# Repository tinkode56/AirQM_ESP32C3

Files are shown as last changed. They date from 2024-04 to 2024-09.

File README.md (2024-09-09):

| Supported Targets | ESP32-C3 |
| --- | --- |

# AirQM_ESP32C3

Air quality monitor using ESP32-C3 and sensors to measure temperature, relative humidity, dust particles, CO2, VOC and NOx.

## Components used

|Item |Buy link |
|---|---|
| ESP32-C3 SuperMini | [Aliexpress](https://www.aliexpress.com/item/1005006451672646.html) |
| senseAir S8 004-0-0053 | [Aliexpress](https://www.aliexpress.com/item/1005005225848074.html) |
| PMS5003 | [Aliexpress](https://www.aliexpress.com/item/1005005967735332.html) |
| SHT45 | [Aliexpress](https://www.aliexpress.com/item/1005003742319869.html) |
| SGP41 | [Aliexpress](https://www.aliexpress.com/item/4000037083952.html) |
| Oled Display | [Aliexpress](https://www.aliexpress.com/item/32950307344.html) |
| Magnets (5x3mm) | [Aliexpress](https://www.aliexpress.com/item/1005001529831924.html) |
| M2 set (M2A) | [Aliexpress](https://www.aliexpress.com/item/1005005467831636.html) |

## Hardware
```
Neodim magnet: 5mm diameter, 3mm height
Heat insert: M2 x 3 x 3.2 for main board
Screws: M2 for PMS5003
```

## Pin connection matrix

```
| ESP32-C3 |  OLED   |  SGP41  |  SHT45  | Senseair S8 | PMS5003  | WS2812 |
|----------|---------|---------|---------|-------------|----------|--------|
| GND      | Pin GND | Pin GND | Pin GND | G0          | PIN2 GND |        |
| 3V3      | Pin 3V3 | Pin 3V3 | Pin 3V3 |             |          |        |
| 5V       |         |         |         | G+          | PIN1 VCC |        |
| GPIO_0   |         |         |         |             | PIN4 TX  |        |
| GPIO_1   |         |         |         |             | PIN5 RX  |        |
| GPIO_2   |         |         |         |             |          |        |
| GPIO_3   |         |         |         |             |          |  DATA  |
| GPIO_4   | Pin SCK |         |         |             |          |        |
| GPIO_5   | Pin DC  |         |         |             |          |        |
| GPIO_6   | Pin SDA |         |         |             |          |        |
| GPIO_7   | Pin CS  |         |         |             |          |        |
| GPIO_8   |         | Pin SDA | Pin SDA |             |          |        |
| GPIO_9   |         | Pin SCL | Pin SCL |             |          |        |
| GPIO_10  | Pin RES |         |         |             |          |        |
| GPIO_20  |         |         |         | UART_TxD    |          |        |
| GPIO_21  |         |         |         | UART_RxD    |          |        |
```

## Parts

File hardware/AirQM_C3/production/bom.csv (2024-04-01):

Designator | Footprint | Quantity | Value | LCSC Part #
C1, C10, C11, C2, C3, C4, C5, C6, C7, C8, C9 | 0603 | 11 | 0.1u
D1 | 0805 | 1 | Alarm_LED
D10, D11, D12, D3, D4, D5, D6, D7, D8, D9 | ws2812_airqm | 10 | WS2812B
D2 | 0805 | 1 | PWM_LED
J1 | PinSocket_1x06_P2.54mm_Vertical | 1 | PMS5003 adapt
J2 | Molex_PicoBlade_53261-0871_1x08-1MP_P1.25mm_Horizontal | 1 | PMS5003
J3 | PinSocket_1x04_P2.54mm_Vertical | 1 | SHT45
J4 | PinSocket_1x04_P2.54mm_Vertical | 1 | SGP41
J5 | PinSocket_1x04_P2.54mm_Vertical | 1 | Spare I2C
J6 | PinSocket_1x07_P2.54mm_Vertical | 1 | OLED
R1, R2 | 0805 | 2 | 4.7k
R3, R4 | 0805 | 2 | 10k
SW1, SW2 | tactile_switch_airqm | 2 | SW_Push
U1 | MODULE_ESP32-C3_SUPERMINI | 1 | ESP32-C3_SUPERMINI
U2 | Senseair_S8_Up | 1 | 004-0-0053

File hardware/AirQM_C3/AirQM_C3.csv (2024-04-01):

Reference | Value | Datasheet | Footprint | Qty | DNP
C1,C2,C3,C4,C5,C6,C7,C8,C9,C10,C11 | 0.1u | ~ | Capacitor_SMD:C_0603_1608Metric | 11
D1 | Alarm_LED | ~ | LED_SMD:LED_0805_2012Metric | 1
D2 | PWM_LED | ~ | LED_SMD:LED_0805_2012Metric | 1
D3,D4,D5,D6,D7,D8,D9,D10,D11,D12 | WS2812B | https://cdn-shop.adafruit.com/datasheets/WS2812B.pdf | ws2812_airqm:ws2812_airqm | 10
J1 | PMS5003 adapt | ~ | Connector_PinSocket_2.54mm:PinSocket_1x06_P2.54mm_Vertical | 1
J2 | PMS5003 | ~ | Connector_Molex:Molex_PicoBlade_53261-0871_1x08-1MP_P1.25mm_Horizontal | 1
J3 | SHT45 | ~ | Connector_PinSocket_2.54mm:PinSocket_1x04_P2.54mm_Vertical | 1
J4 | SGP41 | ~ | Connector_PinSocket_2.54mm:PinSocket_1x04_P2.54mm_Vertical | 1
J5 | Spare I2C | ~ | Connector_PinSocket_2.54mm:PinSocket_1x04_P2.54mm_Vertical | 1
J6 | OLED | ~ | Connector_PinSocket_2.54mm:PinSocket_1x07_P2.54mm_Vertical | 1
R1,R2 | 4.7k | ~ | Resistor_SMD:R_0805_2012Metric | 2
R3,R4 | 10k | ~ | Resistor_SMD:R_0805_2012Metric | 2
SW1,SW2 | SW_Push | ~ | tactile_switch_airqm:tactile_switch_airqm | 2
U1 | ESP32-C3_SUPERMINI |  | esp32c3_supermini:MODULE_ESP32-C3_SUPERMINI | 1
U2 | 004-0-0053 | https://rmtplusstoragesenseair.blob.core.windows.net/docs/publicerat/PSP126.pdf | Sensor:Senseair_S8_Up | 1

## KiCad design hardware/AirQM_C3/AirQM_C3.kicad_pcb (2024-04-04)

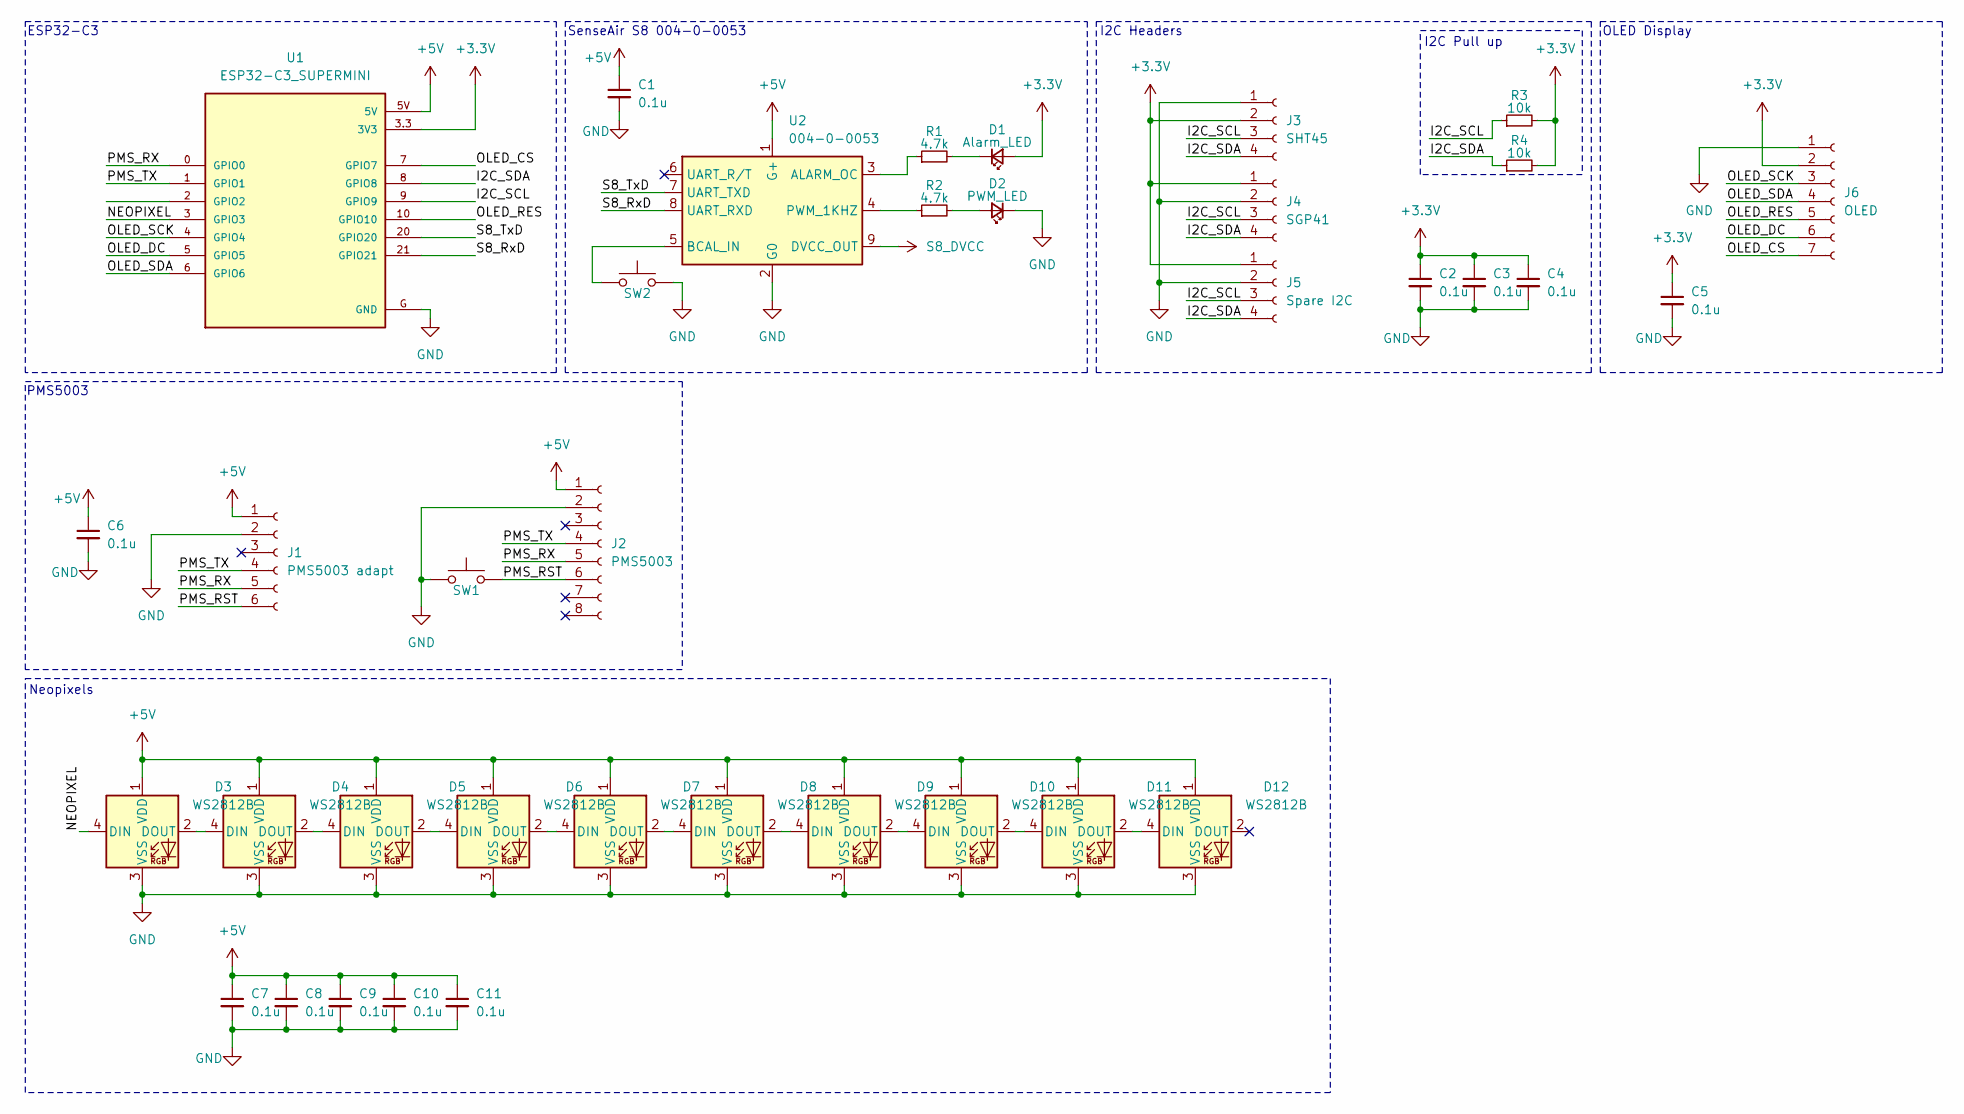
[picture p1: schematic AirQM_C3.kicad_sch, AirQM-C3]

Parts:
C1, C2, C3, C4, C5, C6, C7, C8, C9, C10, C11: 0.1u; C_0603_1608Metric
D1: Alarm_LED; LED_0805_2012Metric
D2: PWM_LED; LED_0805_2012Metric
D3, D4, D5, D6, D7, D8, D9, D10, D11, D12: WS2812B; ws2812_airqm
J1: PMS5003 adapt; PinSocket_1x06_P2.54mm_Vertical
J2: PMS5003; Molex_PicoBlade_53261-0871_1x08-1MP_P1.25mm_Horizontal
J3: SHT45; PinSocket_1x04_P2.54mm_Vertical
J4: SGP41; PinSocket_1x04_P2.54mm_Vertical
J5: Spare I2C; PinSocket_1x04_P2.54mm_Vertical
J6: OLED; PinSocket_1x07_P2.54mm_Vertical
R1, R2: 4.7k; R_0805_2012Metric
R3, R4: 10k; R_0805_2012Metric
SW1, SW2: SW_Push; tactile_switch_airqm
U1: ESP32-C3_SUPERMINI; MODULE_ESP32-C3_SUPERMINI
U2: 004-0-0053; Senseair_S8_Up

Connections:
+3.3V: C2.1, C3.1, C4.1, C5.1, D1.2 (A), J3.2, J4.1, J5.1, J6.2, R3.2, R4.2, U1.3.3 (3V3)
+5V: C1.1, C6.1, C7.1, C8.1, C9.1, C10.1, C11.1, D3.1 (VDD), D4.1 (VDD), D5.1 (VDD), D6.1 (VDD), D7.1 (VDD), D8.1 (VDD), D9.1 (VDD), D10.1 (VDD), D11.1 (VDD), D12.1 (VDD), J1.1, J2.1, U1.5V, U2.1 (G+)
/I2C_SCL: J3.3, J4.3, J5.3, R3.1, U1.9 (GPIO9)
/I2C_SDA: J3.4, J4.4, J5.4, R4.1, U1.8 (GPIO8)
/NEOPIXEL: D3.4 (DIN), U1.3 (GPIO3)
/OLED_CS: J6.7, U1.7 (GPIO7)
/OLED_DC: J6.6, U1.5 (GPIO5)
/OLED_RES: J6.5, U1.10 (GPIO10)
/OLED_SCK: J6.3, U1.4 (GPIO4)
/OLED_SDA: J6.4, U1.6 (GPIO6)
/PMS_RST: J1.6, J2.6, SW1.2
/PMS_RX: J1.5, J2.5, U1.0 (GPIO0)
/PMS_TX: J1.4, J2.4, U1.1 (GPIO1)
/S8_RxD: U1.21 (GPIO21), U2.8 (UART_RXD)
/S8_TxD: U1.20 (GPIO20), U2.7 (UART_TXD)
GND: C1.2, C2.2, C3.2, C4.2, C5.2, C6.2, C7.2, C8.2, C9.2, C10.2, C11.2, D2.1 (K), D3.3 (VSS), D4.3 (VSS), D5.3 (VSS), D6.3 (VSS), D7.3 (VSS), D8.3 (VSS), D9.3 (VSS), D10.3 (VSS), D11.3 (VSS), D12.3 (VSS), J1.2, J2.2, J2.MP, J3.1, J4.2, J5.2, J6.1, SW1.1, SW2.2, U1.G (GND), U2.2 (G0)
unnamed: D1.1 (K), R1.2
unnamed: D2.2 (A), R2.2
unnamed: D3.2 (DOUT), D4.4 (DIN)
unnamed: D4.2 (DOUT), D5.4 (DIN)
unnamed: D5.2 (DOUT), D6.4 (DIN)
unnamed: D6.2 (DOUT), D7.4 (DIN)
unnamed: D7.2 (DOUT), D8.4 (DIN)
unnamed: D8.2 (DOUT), D9.4 (DIN)
unnamed: D9.2 (DOUT), D10.4 (DIN)
unnamed: D10.2 (DOUT), D11.4 (DIN)
unnamed: D11.2 (DOUT), D12.4 (DIN)
unnamed: R1.1, U2.3 (ALARM_OC)
unnamed: SW2.1, U2.5 (BCAL_IN)
unnamed: R2.1, U2.4 (PWM_1KHZ)
S8_DVCC: U2.9 (DVCC_OUT)

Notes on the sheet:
I2C Pull up
I2C Headers
PMS5003
SenseAir S8 004-0-0053
Neopixels
OLED Display
ESP32-C3

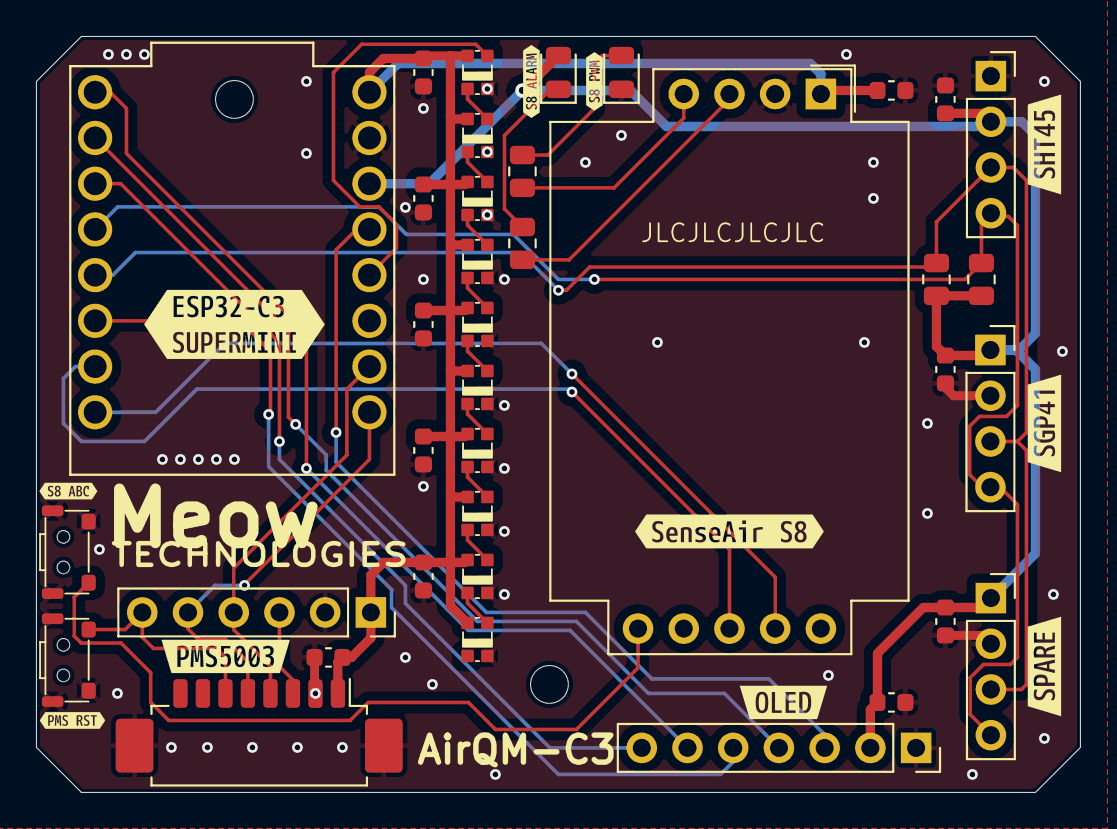
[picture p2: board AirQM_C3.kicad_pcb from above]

Board: 2 copper layers, 58.0 x 42.0 mm, 48 parts (0 on the bottom side), 30 nets.

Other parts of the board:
kibuzzard-660842A3: G***; kibuzzard-660842A3
kibuzzard-660842BE: G***; kibuzzard-660842BE
kibuzzard-660842DD: G***; kibuzzard-660842DD
kibuzzard-660842F1: G***; kibuzzard-660842F1
kibuzzard-6608425C: G***; kibuzzard-6608425C
kibuzzard-6608431D: G***; kibuzzard-6608431D
kibuzzard-66084205: G***; kibuzzard-66084205
kibuzzard-66084210: G***; kibuzzard-66084210
kibuzzard-66084234: G***; kibuzzard-66084234
kibuzzard-66084249: G***; kibuzzard-66084249
kibuzzard-66084324: G***; kibuzzard-66084324

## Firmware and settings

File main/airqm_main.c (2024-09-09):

/*
 * @Author: calin.acr 
 * @Date: 2024-03-15 14:00:51 
 * @Last Modified by: calin.acr
 * @Last Modified time: 2024-09-09 22:23:18
 */

#include <stdio.h>
#include <inttypes.h>
#include "sdkconfig.h"
#include "freertos/FreeRTOS.h"
#include "freertos/task.h"
#include "esp_chip_info.h"
#include "esp_flash.h"
#include "esp_system.h"
#include "oled_display.h"
#include "sgp41.h"
#include "sht45.h"
#include "string.h"
#include "esp_timer.h"
#include "esp_random.h"
#include "sensirion_gas_index_algorithm.h"
#include "senseair_s8.h"
#include "airqm_main.h"
#include "pms5003.h"
#include "nvs_flash.h"
#include "airqm_wifi.h"
#include "airqm_influxdb.h"
#include "esp_sntp.h"
#include "esp_netif_sntp.h"
#include "led_strip.h"
#include "board_support.h"

QueueHandle_t i2cdev_queue;
QueueHandle_t s8_queue;
QueueHandle_t pms_queue;
QueueHandle_t oled_queue;
QueueHandle_t influxdb_queue;

TaskHandle_t xOledTaskHandle = NULL;
TaskHandle_t xI2CDevTaskHandle = NULL;
TaskHandle_t xSenseairTaskHandle = NULL;
TaskHandle_t xPMSTaskHandle = NULL;
TaskHandle_t xDataManagerHandle = NULL;
TaskHandle_t xInfluxManagerHandle = NULL;
TaskHandle_t xNeopixelManagerHandle = NULL;

/* Task stack sizes in bytes */
const uint16_t oled_stack_size = 3000;
const uint16_t i2c_stack_size = 3000;
const uint16_t senseair_stack_size = 2800;
const uint16_t pms_stack_size = 2800;
const uint16_t datmgr_stack_size = 1500;
const uint16_t influx_stack_size = 5000;
const uint16_t neopixel_stack_size = 3000;


void vOledTask(void *pvParameters);
void vI2CDevTask(void *pvParameters);
void vSenseairTask(void *pvParameters);
void vDataManagerTask(void *pvParameters);
void vInfluxDBManagerTask(void *pvParameters);
void vNeopixelManagerTask(void *pvParameters);

void SyncTime(void);


void app_main(void)
{
    /* Initialize display and set the splash screen */
    oled_init();
    // Wifi provisioning and connection init
    airqm_wifiprov_init();

    // Synchronize time from internet
    SyncTime();

    // Create queue between i2c and oled task
    i2cdev_queue = xQueueCreate(3, sizeof(struct I2CDevMessage *));
    s8_queue = xQueueCreate(3, sizeof(uint16_t));
    pms_queue = xQueueCreate(3, sizeof(struct PMSData *));
    oled_queue = xQueueCreate(3, sizeof(AirQM_metrics));
    influxdb_queue = xQueueCreate(3, sizeof(AirQM_metrics));
    
    // Initialize the I2C master bus
    i2c_master_bus_config_t conf = {
        .clk_source = I2C_CLK_SRC_DEFAULT,
        .i2c_port = I2C_NUM_0,
        .sda_io_num = AIRQM_I2C_SDA,
        .scl_io_num = AIRQM_I2C_SCL,
        .glitch_ignore_cnt = 7,
        .flags.enable_internal_pullup = true,
    };
    i2c_master_bus_handle_t bus_handle;
    ESP_ERROR_CHECK(i2c_new_master_bus(&conf, &bus_handle));

    // xTaskCreate(vNeopixelManagerTask, "Neopixel TASK", neopixel_stack_size, NULL, tskAIRQM_NEOPIXEL_PRIORITY, &xNeopixelManagerHandle);
    // configASSERT(xNeopixelManagerHandle);

    xTaskCreate(vDataManagerTask, "DataMgr TASK", datmgr_stack_size, NULL, tskAIRQM_DATAMGR_PRIORITY, &xDataManagerHandle);
    configASSERT(xDataManagerHandle);

    xTaskCreate(vInfluxDBManagerTask, "InfluxMgr TASK", influx_stack_size, NULL, tskAIRQM_INFLUX_PRIORITY, &xInfluxManagerHandle);
    configASSERT(xInfluxManagerHandle);

    xTaskCreate(vI2CDevTask, "I2CDev TASK", i2c_stack_size, (void *)bus_handle, tskAIRQM_I2C_PRIORITY, &xI2CDevTaskHandle);
    configASSERT(xI2CDevTaskHandle);

    xTaskCreate(vOledTask, "OLED TASK", oled_stack_size, NULL, tskAIRQM_DISPLAY_PRIORITY, &xOledTaskHandle);
    configASSERT(xOledTaskHandle);

    xTaskCreate(vSenseairTask, "SENSEAIR TASK", senseair_stack_size, NULL, tskAIRQM_CO2_PRIORITY, &xSenseairTaskHandle);
    configASSERT(xSenseairTaskHandle);

    xTaskCreate(PMS_MainTask, "PMS5003 TASK", pms_stack_size, (void *)pms_queue, tskAIRQM_PMS_PRIORITY, &xPMSTaskHandle);
    configASSERT(xPMSTaskHandle);

    for ( ;; )
    {
        /* Stack size measurements */
        ESP_LOGE("APP_MAIN", "Oled task stack unused bytes: %d", uxTaskGetStackHighWaterMark(xOledTaskHandle));
        ESP_LOGE("APP_MAIN", "I2C task stack unused bytes: %d", uxTaskGetStackHighWaterMark(xI2CDevTaskHandle));
        ESP_LOGE("APP_MAIN", "Senseair task stack unused bytes: %d", uxTaskGetStackHighWaterMark(xSenseairTaskHandle));
        ESP_LOGE("APP_MAIN", "PMS5003 task stack unused bytes: %d", uxTaskGetStackHighWaterMark(xPMSTaskHandle));
        ESP_LOGE("APP_MAIN", "DataMgr task stack unused bytes: %d", uxTaskGetStackHighWaterMark(xDataManagerHandle));
        ESP_LOGE("APP_MAIN", "InfluxMgr task stack unused bytes: %d", uxTaskGetStackHighWaterMark(xInfluxManagerHandle));
        ESP_LOGE("APP_MAIN", "NeopixelMgr task stack unused bytes: %d", uxTaskGetStackHighWaterMark(xNeopixelManagerHandle));
        vTaskDelay(pdMS_TO_TICKS(5000));
    }
}

void vOledTask(void *pvParameters)
{
    ESP_LOGW("OLED_TASK", "Task started");
    
    char temp_buff[7] = "wait  ";
    char hum_buff[7] = "wait  ";
    char co2_buff[6] = "wait ";
    char pm10_buff[6] = "wait ";
    char pm25_buff[6] = "wait ";
    char pm100_buff[6] = "wait ";
    char tvoc_buff[6] = "wait ";
    char nox_buff[6] = "wait ";

    AirQM_metrics allMetrics = { 0 };

    oled_clear_display_buffer();
    
    oled_draw_text("AirQM -> Meow TECH", 0, 1);

    oled_draw_text(temp_buff, 1, 0);
    oled_draw_text("~C", 1, 6);
    oled_draw_text(hum_buff, 1, 12);
    oled_draw_text("%RH", 1, 18);
    
    oled_draw_text("CO2", 2, 0);
    oled_draw_text(co2_buff, 2, 7);
    oled_draw_text("ppm", 2, 14);

    oled_draw_text("PM1.0", 3, 0);
    oled_draw_text(pm10_buff, 3, 7);
    oled_draw_text("ug/m3", 3, 14);

    oled_draw_text("PM2.5", 4, 0);
    oled_draw_text(pm25_buff, 4, 7);
    oled_draw_text("ug/m3", 4, 14);

    oled_draw_text("PM10", 5, 0);
    oled_draw_text(pm100_buff, 5, 7);
    oled_draw_text("ug/m3", 5, 14);

    oled_draw_text("VOC", 6, 0);
    oled_draw_text(tvoc_buff, 6, 7);

    oled_draw_text("NOx", 7, 0);
    oled_draw_text(nox_buff, 7, 7);

    oled_flush();

    for( ;; )
    {
        // Task body
        if (oled_queue != 0)
        {
            if (xQueueReceive(oled_queue, &(allMetrics), (TickType_t) 10))
            {
                // Convert values to strings
                sprintf(temp_buff, "%6.2f", allMetrics.temp_phy);
                sprintf(hum_buff, "%6.2f", allMetrics.hum_phy);
                sprintf(tvoc_buff, "%5ld", allMetrics.voc_index_value);
                sprintf(nox_buff, "%5ld", allMetrics.nox_index_value);
                sprintf(co2_buff, "%5d", allMetrics.co2_val);
                sprintf(pm10_buff, "%5d", allMetrics.pm10_std);
                sprintf(pm25_buff, "%5d", allMetrics.pm25_std);
                sprintf(pm100_buff, "%5d", allMetrics.pm100_std);
                // Write to GDDRAM
                oled_draw_text(temp_buff, 1, 0);
                oled_draw_text(hum_buff, 1, 12);
                oled_draw_text(tvoc_buff, 6, 7);
                oled_draw_text(nox_buff, 7, 7);
                oled_draw_text(co2_buff, 2, 7);
                oled_draw_text(pm10_buff, 3, 7);
                oled_draw_text(pm25_buff, 4, 7);
                oled_draw_text(pm100_buff, 5, 7);
                // Flush GDDRAM to display
                oled_flush();
            }
            
        }
    }
}

void vI2CDevTask(void *pvParameters)
{
    ESP_LOGW("I2C TASK", "Task started");

    struct I2CDevMessage *pxMessage;
    i2c_master_bus_handle_t bus_handle;

    bus_handle = (i2c_master_bus_handle_t) pvParameters;
    pxMessage = &xI2CDevMessage;

    uint8_t conditioning_counter = 0;

    uint16_t sht45_temp_raw;
    uint16_t sht45_hum_raw;
    uint16_t sgp41_voc_raw;
    uint16_t sgp41_nox_raw;

    GasIndexAlgorithmParams voc_params;
    GasIndexAlgorithmParams nox_params;

    GasIndexAlgorithm_init(&voc_params, GasIndexAlgorithm_ALGORITHM_TYPE_VOC);
    GasIndexAlgorithm_init(&nox_params, GasIndexAlgorithm_ALGORITHM_TYPE_NOX);

    // SHT45 init and reset
    SHT45_Init(&bus_handle);
    SHT45_SoftReset();


    // SGP41 init
    SGP41_Init(&bus_handle);

    // SGP41 conditioning (1 command every second, max 10 seconds)
    while (conditioning_counter < 10)
    {
        SGP41_ExecuteConditioning(&sgp41_voc_raw);
        // Count as conditioning iteration done
        conditioning_counter++;
        // Wait one second
        vTaskDelay(pdMS_TO_TICKS(1000));
    }
    
    for ( ;; )
    {
        // Task body
        // Read data from I2C sensors
        SHT45_Read(SHT45_MODE_HIGH_PRECISION_NO_HEATER, &sht45_temp_raw, &pxMessage->temp_phy, &sht45_hum_raw, &pxMessage->hum_phy);
        SGP41_MeasureRawSignals(sht45_temp_raw, sht45_hum_raw, &sgp41_voc_raw, &sgp41_nox_raw);

        // ESP_LOGI("SGP", "RAW VOC %d, NOx %d", sgp41_voc_raw, sgp41_nox_raw);

        // Use Sensirion Algorithm to get VOC and NOx indices
        GasIndexAlgorithm_process(&voc_params, sgp41_voc_raw, &pxMessage->voc_index_value);
        GasIndexAlgorithm_process(&nox_params, sgp41_nox_raw, &pxMessage->nox_index_value);
        
        // ESP_LOGI("SGP", "VOC %ld, NOx %ld", pxMessage->voc_index_value, pxMessage->nox_index_value);

        if (i2cdev_queue != 0)
        {
            if(xQueueSendToBack(i2cdev_queue, (void *) &pxMessage, (TickType_t) 0) != pdPASS)
            {
                ESP_LOGE("I2C TASK", "Failed to post the message");
            }
        }
        
        vTaskDelay(pdMS_TO_TICKS(1000));
        

        // taskYIELD();
    }
}


void vSenseairTask(void *pvParameters)
{
    ESP_LOGW("S8 TASK", "Task started");
    // uint8_t cal_status;
    uint16_t co2_value, status;
    uint16_t abc, memmap_ver, fw_ver;
    uint32_t sens_type_id, sens_id;
    
    SenseairS8_Init();
    
    // cal_status = S8_BgCalibration(CO2_BG_CAL);
    // ESP_LOGI("S8 TASK", "Calibration status %d", cal_status);
    
    S8_ReadSensorTypeID(&sens_type_id);
    ESP_LOGI("S8 TASK", "Sensor Type ID 0x%08jx", (uintmax_t)sens_type_id);

    S8_ReadABC(&abc);
    ESP_LOGI("S8 TASK", "ABC period 0x%04x, %d hours", abc, abc);

    S8_ReadMemMapVers(&memmap_ver);
    ESP_LOGI("S8 TASK", "Memory Mapping ver 0x%04x", memmap_ver);

    S8_ReadFWVers(&fw_ver);
    ESP_LOGI("S8 TASK", "Firmware ver 0x%04x", fw_ver);

    S8_ReadSensorID(&sens_id);
    ESP_LOGI("S8 TASK", "Sensor ID (SN) 0x%08jx", (uintmax_t)sens_id);
    
    for( ;; )
    {
        vTaskDelay(pdMS_TO_TICKS(4000));
        S8_ReadCO2andStatus(&co2_value, &status);
        
        if ((s8_queue != 0) && (!CHECK_ERROR_ANY(status)))
        {
            if (xQueueSendToBack(s8_queue, (void *) &co2_value, (TickType_t) 0) != pdTRUE)
            {
                ESP_LOGE("S8 TASK", "Failed to post the message");
            }
        }
    }
}

void SyncTime(void)
{
    // Synchronize time with NTP
    if ( esp_sntp_enabled() ) {
        esp_sntp_stop();
    }
    esp_sntp_setoperatingmode(ESP_SNTP_OPMODE_POLL);
    ESP_LOGI("NTP-Sync", "Getting time via NTP from: %s", CONFIG_AIRQM_NTP_SERVER);
    esp_sntp_setservername(0, CONFIG_AIRQM_NTP_SERVER);
    
    const int total_max_retries = 3;
    int total_retries = 0;
    time_t now = 0;
    struct tm timeinfo = { 0 };
    do {
        esp_sntp_init();

        int retry = 0;

        // NTP request is sent every 15 seconds, so wait 25 seconds for sync.
        const int retry_count = 10;
        while ((sntp_get_sync_status() == SNTP_SYNC_STATUS_RESET) && (++retry < retry_count)) {
            ESP_LOGI("NTP-Sync", "Waiting for system time to be set... (%d/%d)", retry, retry_count);
            vTaskDelay(2000 / portTICK_PERIOD_MS);
        }
        if (retry == retry_count) {
            total_retries += 1;
            esp_sntp_stop();
        } else {
            break;
        }
    } while (total_retries < total_max_retries);
    assert(total_retries < total_max_retries);
    // update 'now' variable with current time
    time(&now);

    // Set timezone
    ESP_LOGI("NTP-Sync", "Timezone is set to: %s", CONFIG_AIRQM_NTP_TZ);
    setenv("TZ", CONFIG_AIRQM_NTP_TZ, 1);
    tzset();
    localtime_r(&now, &timeinfo);

    char strftime_buf[64];
    strftime(strftime_buf, sizeof(strftime_buf), "%c", &timeinfo);
    ESP_LOGI("NTP-Sync", "The current date/time is: %s", strftime_buf);

}

void vDataManagerTask(void *pvParameters)
{
    struct I2CDevMessage *pxMessage;
    uint16_t co2_ppm;
    struct PMSRecvMessage *pxPMSMessage;

    AirQM_metrics allMetrics = { 0 };
    bool isAnyMetricUpdated = false;

    TickType_t xLastWakeTime;
    // Frequency of data write in InfluxDB (1 min = 60000 ms)
    const TickType_t xFrequency = pdMS_TO_TICKS(60000);

    xLastWakeTime = xTaskGetTickCount();

    for ( ;; )
    {
        if (i2cdev_queue != 0)
        {
            if (xQueueReceive(i2cdev_queue, &(pxMessage), (TickType_t) 10))
            {
                // Update allMetrict to be sent to InfluxDB
                allMetrics.temp_phy = pxMessage->temp_phy;
                allMetrics.hum_phy = pxMessage->hum_phy;
                allMetrics.voc_index_value = pxMessage->voc_index_value;
                allMetrics.nox_index_value = pxMessage->nox_index_value;
                // Signal metric values have updated
                isAnyMetricUpdated = true;
            }
        }

        if (s8_queue != 0)
        {
            if (xQueueReceive(s8_queue, &co2_ppm, (TickType_t) 10))
            {
                // Update allMetrict to be sent to InfluxDB
                allMetrics.co2_val = co2_ppm;
                // Signal metric values have updated
                isAnyMetricUpdated = true;
            }
        }

        if (pms_queue != 0)
        {
            if (xQueueReceive(pms_queue, &(pxPMSMessage), (TickType_t) 10))
            {
                // Update allMetrict to be sent to InfluxDB
                allMetrics.pm10_std = pxPMSMessage->pm10_std;
                allMetrics.pm25_std = pxPMSMessage->pm25_std;
                allMetrics.pm100_std = pxPMSMessage->pm100_std;
                allMetrics.pm10_env = pxPMSMessage->pm10_env;
                allMetrics.pm25_env = pxPMSMessage->pm25_env;
                allMetrics.pm100_env = pxPMSMessage->pm100_env;
                allMetrics.particles_03um = pxPMSMessage->particles_03um;
                allMetrics.particles_05um = pxPMSMessage->particles_05um;
                allMetrics.particles_10um = pxPMSMessage->particles_10um;
                allMetrics.particles_25um = pxPMSMessage->particles_25um;
                allMetrics.particles_50um = pxPMSMessage->particles_50um;
                allMetrics.particles_100um = pxPMSMessage->particles_100um;
                // Signal metric values have updated
                isAnyMetricUpdated = true;
            }
        }

        if (isAnyMetricUpdated)
        {
            // Send data to OLED
            if (oled_queue != 0)
            {
                if(xQueueSendToBack(oled_queue, (void *) &allMetrics, (TickType_t) 0) != pdPASS)
                {
                    ESP_LOGE("AqmDataManager", "Failed to post the message to oled queue");
                }
                else
                {
                    isAnyMetricUpdated = false;
                }
            }
        }

        if (xTaskGetTickCount() - xLastWakeTime >= xFrequency)
        {
            // Send data to InfluxDB Manager
            if (influxdb_queue != 0)
            {
                if(xQueueSendToBack(influxdb_queue, (void *) &allMetrics, (TickType_t) 0) != pdPASS)
                {
                    ESP_LOGE("AqmDataManager", "Failed to post the message to influxdb queue");
                }
            }
            // Update last wake time with current time
            xLastWakeTime = xTaskGetTickCount();
        }
    }
    
}

void vInfluxDBManagerTask(void *pvParameters)
{
    AirQM_metrics allMetrics = { 0 };

    for ( ;; )
    {
        if (influxdb_queue != 0)
        {
            if (xQueueReceive(influxdb_queue, &(allMetrics), (TickType_t) 10))
            {
                // Write data into InfluxDB
                write_influxdb(&allMetrics);
            }
        }
    }
}

#define PIXEL_COUNT 10

void vNeopixelManagerTask(void *pvParameters)
{  
    ESP_LOGW("NEOPIXEL TASK", "Task started");

    /* LED strip initialization with the GPIO and pixels number*/
    led_strip_config_t strip_config = {
        .strip_gpio_num = AIRQM_NEOPIXEL_PIN, // The GPIO that connected to the LED strip's data line
        .max_leds = PIXEL_COUNT, // The number of LEDs in the strip,
        .led_pixel_format = LED_PIXEL_FORMAT_GRB, // Pixel format of your LED strip
        .led_model = LED_MODEL_WS2812, // LED strip model
        .flags.invert_out = false, // whether to invert the output signal (useful when your hardware has a level inverter)
    };

    led_strip_rmt_config_t rmt_config = {
        .clk_src = RMT_CLK_SRC_DEFAULT, // different clock source can lead to different power consumption
        .resolution_hz = 10 * 1000 * 1000, // 10MHz
        .flags.with_dma = false, // whether to enable the DMA feature
    };

    // LED Strip object handle
    led_strip_handle_t led_strip;
    ESP_ERROR_CHECK(led_strip_new_rmt_device(&strip_config, &rmt_config, &led_strip));
    ESP_LOGI("NEOPIXEL TASK", "Created LED strip object with RMT backend");
    uint8_t colors[30] = {
        0x10, 0x00, 0x00, //LED0
        0x10, 0x08, 0x00, //LED1
        0x10, 0x10, 0x00, //LED2
        0x08, 0x10, 0x00, //LED3
        0x00, 0x10, 0x00, //LED4
        0x00, 0x10, 0x08, //LED5
        0x00, 0x10, 0x10, //LED6
        0x00, 0x08, 0x10, //LED7
        0x00, 0x00, 0x10, //LED8
        0x08, 0x00, 0x10  //LED9
        };

    for (int i = 0; i < PIXEL_COUNT; i++) {
        ESP_ERROR_CHECK(led_strip_set_pixel(led_strip, i, colors[i*3], colors[(i*3)+1], colors[(i*3)+2]));
    }

    /* Refresh the strip to send data */
    ESP_ERROR_CHECK(led_strip_refresh(led_strip));

    for ( ;; )
    {
        vTaskDelay(pdMS_TO_TICKS(5000));
    }
}

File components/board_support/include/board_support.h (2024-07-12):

/*
 * @Author: calin.acr 
 * @Date: 2024-07-09 20:23:52 
 * @Last Modified by: calin.acr
 * @Last Modified time: 2024-07-09 20:41:47
 */

#if !defined(_BOARD_SUPPORT_H)
#define _BOARD_SUPPORT_H

#include "driver/gpio.h"

/* OLED PINS */
#define AIRQM_OLED_SCK_PIN      GPIO_NUM_4
#define AIRQM_OLED_MOSI_PIN     GPIO_NUM_6
#define AIRQM_OLED_CS_PIN       GPIO_NUM_7
#define AIRQM_OLED_DC_PIN       GPIO_NUM_5
#define AIRQM_OLED_RESET_PIN    GPIO_NUM_10

/* PMS5003 PINS */
#define AIRQM_PMS_UART_TX_PIN   GPIO_NUM_1
#define AIRQM_PMS_UART_RX_PIN   GPIO_NUM_0

/* SenseairS8 PINS */
#define AIRQM_SENSEAIR_TX_PIN   GPIO_NUM_21
#define AIRQM_SENSEAIR_RX_PIN   GPIO_NUM_20

/* SGP41 and SHT45 PINS */
#define AIRQM_I2C_SCL   GPIO_NUM_9
#define AIRQM_I2C_SDA   GPIO_NUM_8

/* NEOPIXEL PIN */
#define AIRQM_NEOPIXEL_PIN  GPIO_NUM_3

#endif // _BOARD_SUPPORT_H

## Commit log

2024-03-19 Drop MODBUS library usage, will implement dedicated solution specific to sensor
2024-03-21 Complete driver for SenseairS8 CO2 sensor Reintroduced freemodbus component
2024-03-23 Integrate driver for PMS5003 Add documentation for each device used Test code for sending periodic messages to a future WiFi task Code cleanup Updates to README
2024-03-25 Added WiFi connectivity, NTP time sync, write data to InfluxDB
    [partitions.csv]
2024-03-27 Create dedicated tasks for handling sensor data One task responsible for receiving all sensor data and sending to OLED task in order to update the screen One task responsible for handling time synchr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
2024-04-01 Task stack resize, update readme KiCad project added with schematic and PCB
    [AirQM_C3.csv, AirQM_C3.kicad_pcb, AirQM_C3.kicad_sch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]
2024-04-04 Hardware update
    [AirQM_C3.kicad_pcb]
2024-07-12 Board configuration file created
2024-07-18 Multiple changes to architecture Add correct task priorities Sync NTP at boot only instead of every minute, let lwIP sync automatically each hour
    [airqm_main.c, sgp41.c]
2024-09-09 Splash screen implementation Now until the connection to WiFi is done and the first set of data is acquired from sensors, the display shows a custom logo
